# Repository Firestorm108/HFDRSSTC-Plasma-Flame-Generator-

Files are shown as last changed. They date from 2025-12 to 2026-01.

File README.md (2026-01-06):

# HFDRSSTC-Plasma-Flame-Generator-
A plasma flame generator, or high frequency dual resonant solid state tesla coil! It uses some really clever electronics to achieve this, and is a staple in plasma physics, being able to produce 4" flames at less than 500W of power. It runs off mains 120VAC, and is based of the IRFP460 power MOSFET. Inspired and derived from the works of Styropyro, Steve Ward, Plasma Channel, and Elecrow. 









# Bill of Materials (BOM)

| Item | Price | Link |
|---|---:|---|
| Screw Terminals | $2 | https://www.aliexpress.us/item/3256806456550715.html |
| Rectifiers | $2 | https://www.aliexpress.us/item/3256807891203177.htm |
| 1W Transformer | $10 | https://www.aliexpress.us/item/2255800847488657.html |
| 35V 4700uF Electrolytics | $5 | https://www.aliexpress.us/item/3256801889213205.html |
| LM7812 Voltage Regulator | $3 | https://www.aliexpress.us/item/3256806033968605.html |
| 16V 330uF Electrolytics | $4 | https://www.aliexpress.us/item/3256801889213205.html |
| 250V 330uF Electrolytics | $5 | https://www.aliexpress.us/item/3256801890525893.html |
| 10uH Inductors | $5 | https://www.aliexpress.us/item/3256806693688205.html |
| IRFP460 MOSFETs | $3 | https://www.aliexpress.us/item/3256806648557481.html |
| TO-247 Heatsink | $1 | https://www.aliexpress.us/item/3256805656895845.html |
| PVC Coupler *(Out of Pocket)* | $5 | https://www.amazon.com/dp/B0DP5XQ1QM |
| 1kV 0.1uF Film Capacitors | $3 | https://www.aliexpress.us/item/3256808548022383.html |
| 10K Potentiometers | $3 | https://www.aliexpress.us/item/3256809269867205.html |
| 28AWG Magnet Wire *(Out of Pocket)* | $12 | https://www.amazon.com/dp/B07DYF53ZN |
| 18AWG Primary Wire | $3 | https://www.aliexpress.us/item/2251832439120214.html |
| Perfboard | $3 | https://www.aliexpress.us/item/3256806802956681.html |

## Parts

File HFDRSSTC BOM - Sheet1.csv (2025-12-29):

Item | Price | Link
Screw Terminals | $2 | https://www.aliexpress.us/item/3256806456550715.html
Rectifiers | $2 | https://www.aliexpress.us/item/3256807891203177.htm
1W Transformer | $13 | https://www.aliexpress.us/item/3256804283311436.html?
35V 4700uF Electrolytics | $5 | https://www.aliexpress.us/item/3256801889213205.html
LM7812 Voltage Regulator | $3 | https://www.aliexpress.us/item/3256806033968605.html
16V 330uF Electrolytics | $4 | https://www.aliexpress.us/item/3256801889213205.html
250V 330uF Electrolytics | $5 | https://www.aliexpress.us/item/3256801890525893.html
10uH Inductors | $8 | https://www.aliexpress.us/item/3256802493205525.html
IRFP460 MOSFETs | $3 | https://www.aliexpress.us/item/3256806648557481.html
TO-247 Heatsink | $1 | https://www.aliexpress.us/item/3256805656895845.html
PVC Coupler | $5 | https://www.amazon.com/Coupling-Fittings-Contractor-Connectors-Structure/dp/B0DP5XQ1QM/
2kV 0.1uF Film Capacitors | $5 | https://www.aliexpress.us/item/2251832822202530.htm
10K Potentiometers | $3 | https://www.aliexpress.us/item/3256809269867205.html
28AWG Magnet Wire | $12 | https://www.amazon.com/BNTECHGO-AWG-Magnet-Wire-Transformers/dp/B07DYF53ZN/
18AWG Primary Wire | $3 | https://www.aliexpress.us/item/2251832439120214.html
Perfboard | $3 | https://www.aliexpress.us/item/3256806802956681.html
 | $75

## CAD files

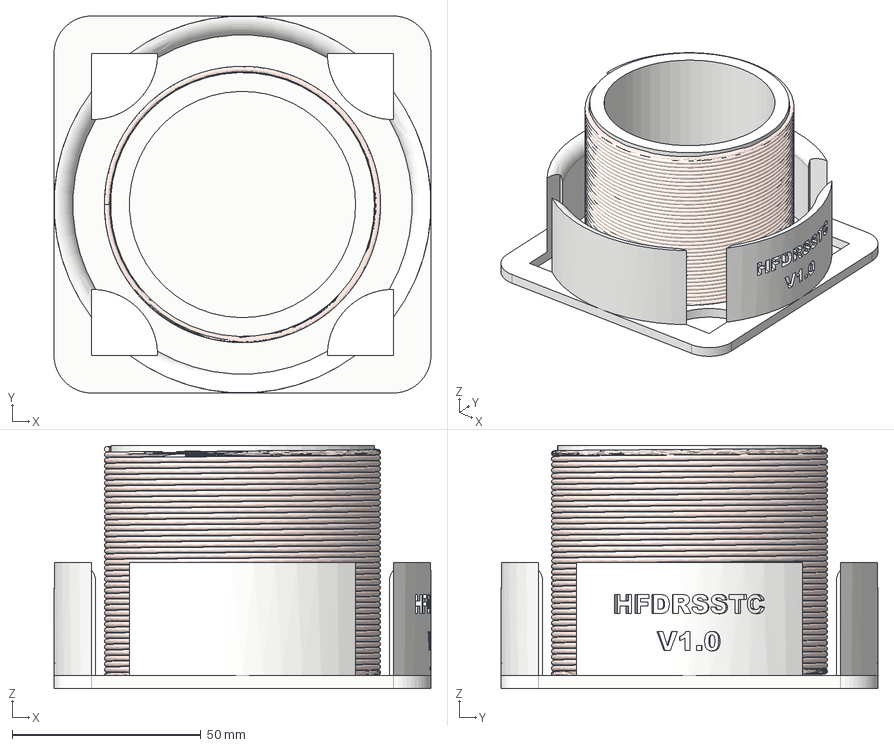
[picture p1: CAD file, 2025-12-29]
PlasmaFlameGeneratorAssembly.step
100.0 x 100.0 x 64.5 mm

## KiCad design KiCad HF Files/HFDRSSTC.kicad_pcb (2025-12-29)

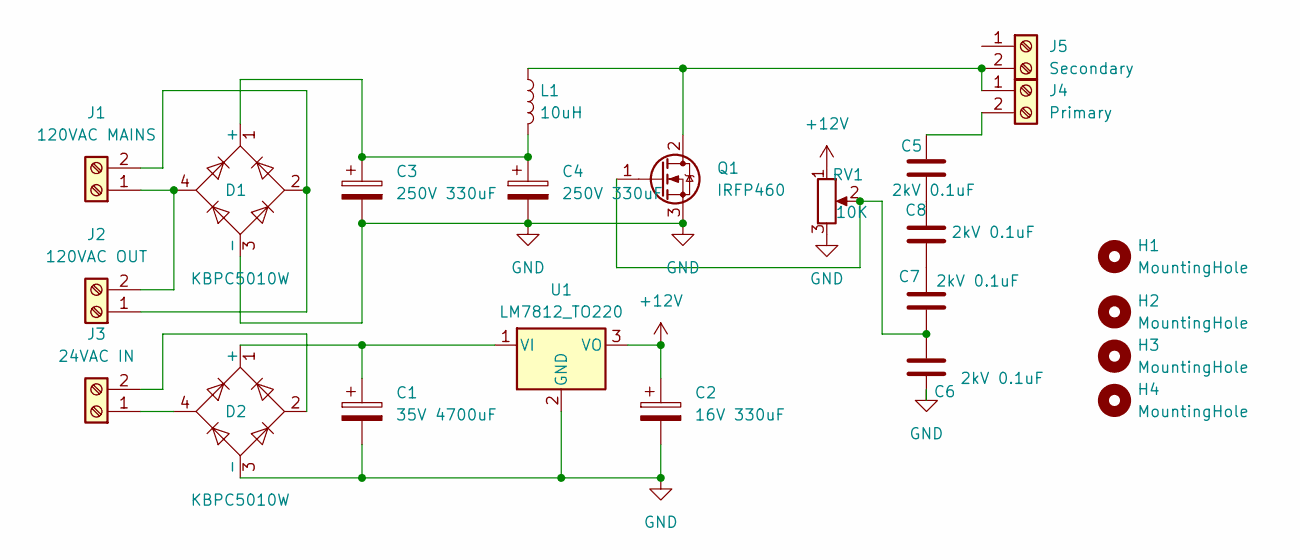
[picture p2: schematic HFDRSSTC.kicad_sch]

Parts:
C1: 35V 4700uF; C_Radial_D18.0mm_H35.5mm_P7.50mm
C2: 16V 330uF; C_Radial_D10.0mm_H16.0mm_P5.00mm
C3, C4: 250V 330uF; C_Radial_D18.0mm_H35.5mm_P7.50mm
C5, C6, C7, C8: 2kV 0.1uF; C_Rect_L7.2mm_W2.5mm_P5.00mm_FKS2_FKP2_MKS2_MKP2
D1, D2: KBPC5010W; Diode_Bridge_GeneSiC_KBPC_W
H1, H2, H3, H4: MountingHole; MountingHole_3.2mm_M3
J1: 120VAC MAINS; TE_282837-2
J2: 120VAC OUT; TE_282837-2
J3: 24VAC IN; TE_282837-2
J4: Primary; TE_282837-2
J5: Secondary; TE_282837-2
L1: 10uH; L_Toroid_Horizontal_D16.8mm_P14.70mm_Vishay_TJ3_BigPads
Q1: IRFP460; TO-247-3_Vertical
RV1: 10K; Potentiometer_TT_P0915N
U1: LM7812_TO220; TO-220-3_Vertical

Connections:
+12V: C2.1, RV1.1, U1.3 (VO)
GND: C1.2, C2.2, C3.2, C4.2, C6.2, D1.3 (-), D2.3 (-), Q1.3 (S), RV1.3, U1.2 (GND)
unnamed: C5.2, C8.1
unnamed: C7.1, C8.2
unnamed: C3.1, C4.1, D1.1 (+), L1.2
unnamed: C1.1, D2.1 (+), U1.1 (VI)
unnamed: D1.4, J1.1, J2.2
unnamed: D1.2, J1.2, J2.1
unnamed: D2.4, J3.1
unnamed: D2.2, J3.2
unnamed: J4.1, J5.2, L1.1, Q1.2 (D)
unnamed: C5.1, J4.2
unnamed: C6.1, C7.2, Q1.1 (G), RV1.2

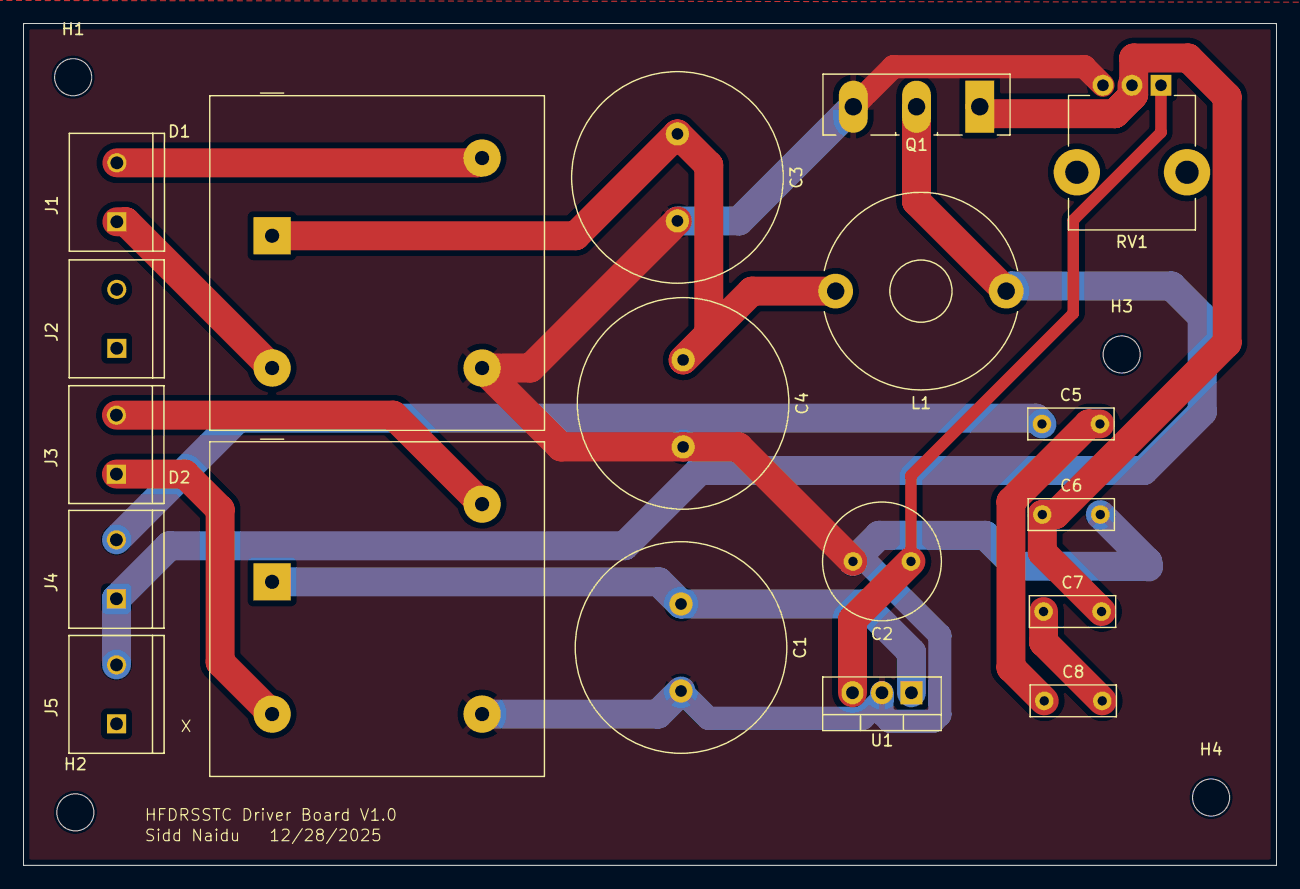
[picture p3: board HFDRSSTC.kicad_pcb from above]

Board: 2 copper layers, 108.0 x 72.6 mm, 23 parts (0 on the bottom side), 13 nets.

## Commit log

2025-12-29 Update and rename HFDRSSTC BOM - Sheet1.csv to BOM.csv
    [BOM.csv]
2026-01-06 Update and rename HFDRSSTC BOM - Sheet1 (1).csv to BOM.csv
    [BOM.csv]
2026-01-06 Revise BOM format in README.md
    Updated the Bill of Materials (BOM) section to use a table format.
